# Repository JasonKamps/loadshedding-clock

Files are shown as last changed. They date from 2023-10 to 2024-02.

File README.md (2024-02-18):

# Loadshedding Clock

A timer that counts down to the next scheduled blackout.

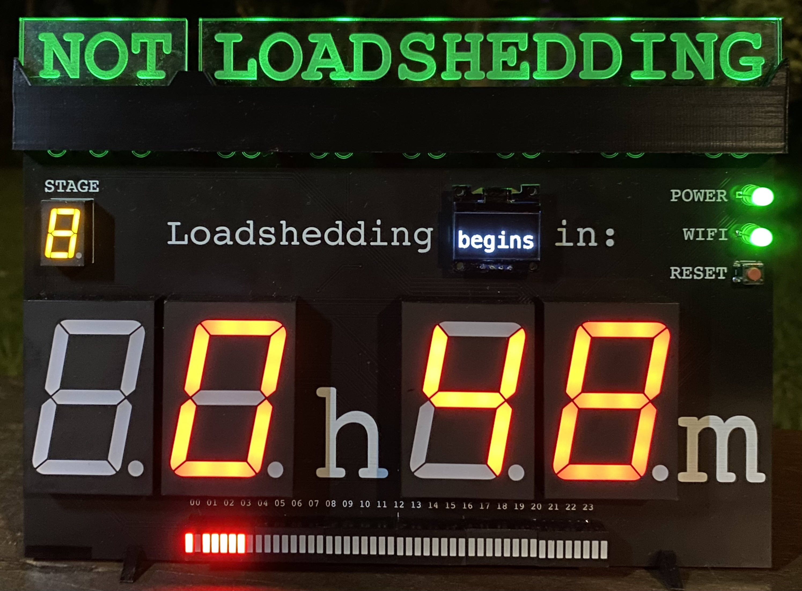
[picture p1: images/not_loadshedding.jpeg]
Front view not loadshedding

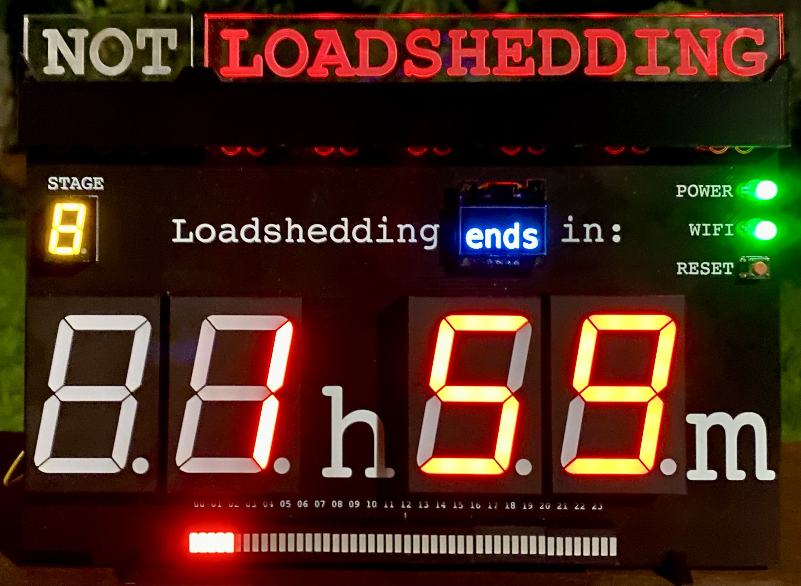
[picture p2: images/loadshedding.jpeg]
Front view loadshedding

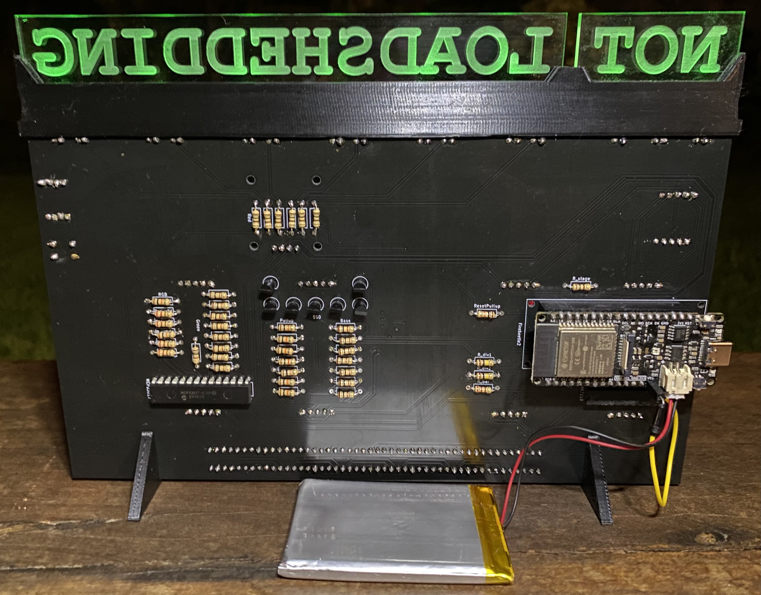
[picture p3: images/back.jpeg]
Back view

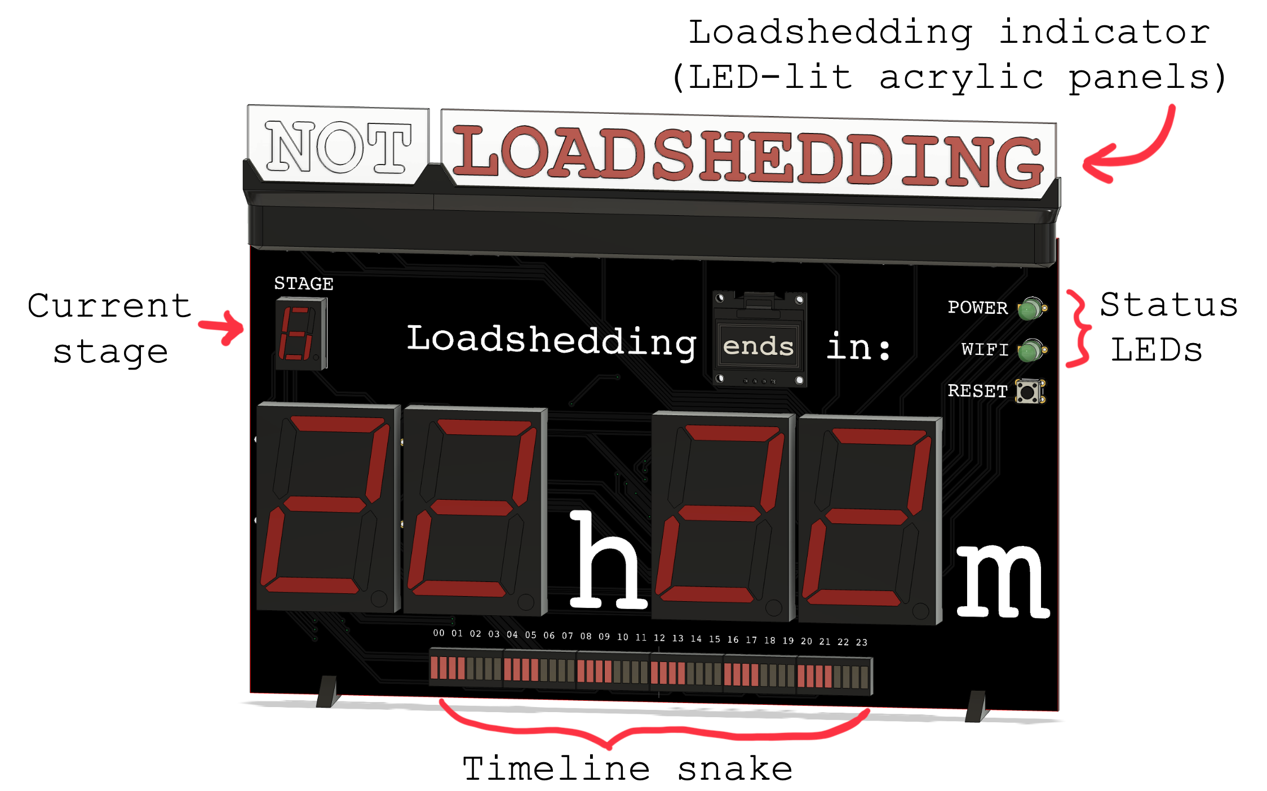
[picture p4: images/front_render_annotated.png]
CAD render


The clock is based on an ESP32 microcontroller, and it obtains loadshedding information from the [EskomSePush API](https://eskomsepush.gumroad.com/l/api).

All code is written in C++ using the [Arduino framework](https://www.arduino.cc/reference/en/) and [PlatformIO](https://platformio.org/). The code is available in [/loadshedding-clock-code/src](./loadshedding-clock-code/src).

The PCB schematics and board layouts can be found in [/PCB](./PCB).

CAD files for the 3D-printable parts can be found in [/3D](./3D).

## Why did I make this?

In South Africa, our national power utility (Eskom) [fails to generate](https://en.wikipedia.org/wiki/South_African_energy_crisis) sufficient electricity to supply the entire country with power. As a result, rolling blackouts have been implemented to ration electricity. Each day, regions of the country are disconnected from the power grid for hours at a time. Any given area typically experiences blackouts lasting 2 to 4 hours, multiple times each day. 

Fortunately, these blackout events are scheduled in advance. The timings of the blackouts change daily, and it can be challenging to keep track of when loadshedding will occur. Many South Africans rely on the [EskomSePush](https://esp.info/) app to stay informed about the loadshedding in their area. I wanted to take this one step further and make it even easier to stay informed. By simply glancing at the loadshedding clock, one can immediately see when the next blackout will occur.

## How does it work?

The clock is based on an ESP32 microcontroller. It connects to the internet via WiFi, and it obtains loadshedding information from the [EskomSePush API](https://eskomsepush.gumroad.com/l/api). The clock is powered by a 5V USB power supply, and it is equipped with a battery backup. 

When the clock is powered on for the first time, it broadcasts its own WiFi network. When the user connects to this network and visits a site hosted by the clock, they can input their WiFi credentials, suburb, and EskomSePush API key.

The clock then displays the loadshedding information for the given suburb, automatically updating its schedule every 30 minutes. If the internet connection is lost, it will continue to display the last schedule that it received from the API.

## What's next?

Future versions may include the following:

- [x] ~~Get the clock working~~
- [x] ~~LED timeline~~
- [x] ~~LED-lit acrylic panel~~
- [x] ~~Design PCB~~
- [ ] Simplified 7-segment display circuitry
- [ ] Notification buzzer
- [ ] Capacitive touch input

## Bill of Materials

| Part | Quantity |
|---| -- |
| [FireBeetle 2 ESP32 Microcontroller](https://www.robotics.org.za/DFR0654) | 1 |
| [3.7V LiPo Battery](https://www.robotics.org.za/DTP605068) | 1 |
| [I2C OLED Display](https://www.robotics.org.za/OLED096W) | 1 |
| [MCP23017 IO Expander](https://www.robotics.org.za/MCP23017) | 1 |
| [MAX7219 Display Driver](https://www.robotics.org.za/MAX7219-DIP) | 1 |
| [7 Segment Display 1.8" Common Cathode](https://www.robotics.org.za/7SEG-018-GRE) | 4 |
| [7 Segment Display 0.56" Common Cathode](https://www.robotics.org.za/7SEG-056-RED) | 1 |
| [BC557 PNP Transistor](https://www.robotics.org.za/BC557) | 7 |
| [Bar graph LED](https://www.robotics.org.za/BAR8-RED) | 6 |
| [Green 5mm LED](https://www.robotics.org.za/LED-05-GRN-17) | 9 |
| [Red 5mm LED](https://www.robotics.org.za/LED-RED-5MM) | 6 |
| [Push button](https://www.robotics.org.za/TAC-66-H) | 1 |
| [RGB LED](https://www.robotics.org.za/RGB-8MM-CC) | 2 |
| [Adjustable DC power supply](https://www.robotics.org.za/CJ-615) | 1 |
| [DC jack to USB C converter](https://www.robotics.org.za/JACK-USBC) | 1 |
| [100kΩ resistor](https://www.robotics.org.za/RES-100K-50) | 2 |
| [10kΩ resistor](https://www.robotics.org.za/RES-10K-025) | 8 |
| [1kΩ resistor](https://www.robotics.org.za/RES-1K-50) | 18 |
| [220Ω resistor](https://www.robotics.org.za/RES-220E-50) | 5 |
| [100Ω resistor](https://www.robotics.org.za/RES-100E-50) | 7 |

## Video overview
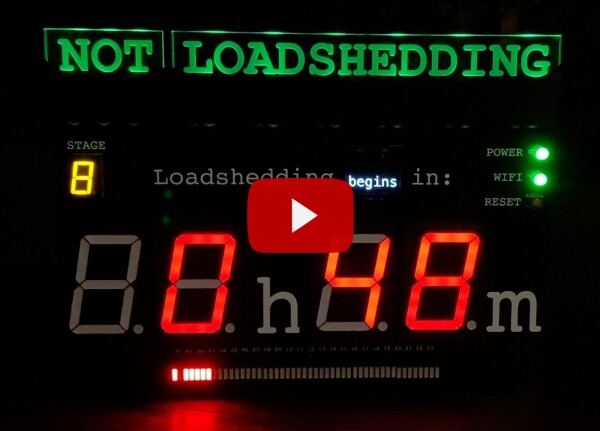
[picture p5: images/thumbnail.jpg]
I made a loadshedding clock (https://youtu.be/v7MFmr7yhXo "I made a loadshedding clock")


## Breadboard Prototype
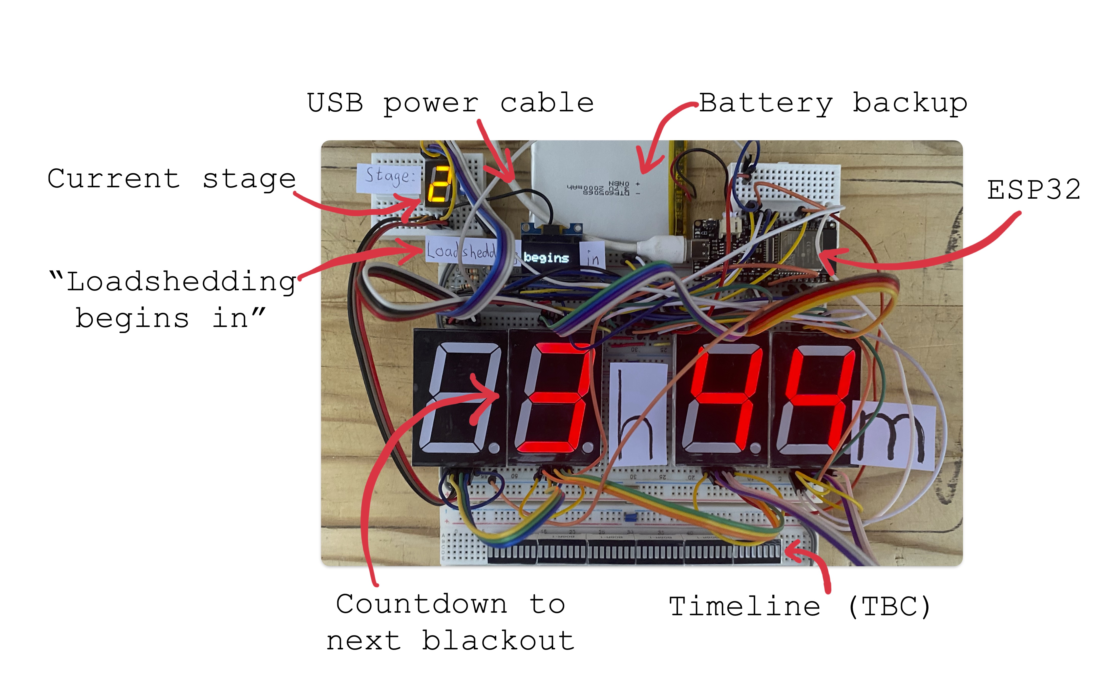
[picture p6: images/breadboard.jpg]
Breadboard prototype


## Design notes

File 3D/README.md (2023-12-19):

## 3D CAD files

This directory contains the 3D CAD files for the supporting parts of the loadshedding clock.

The files were designed in [Fusion 360](https://www.autodesk.com/products/fusion-360/overview).

## Loadshedding indicator adapter and Feet

The loadshedding indicator adapter is a 3D-printed part that allows the loadshedding indicator (acrylic panels) to be mounted on the clock.

The feet are 3D-printed parts that allow the clock to stand upright.

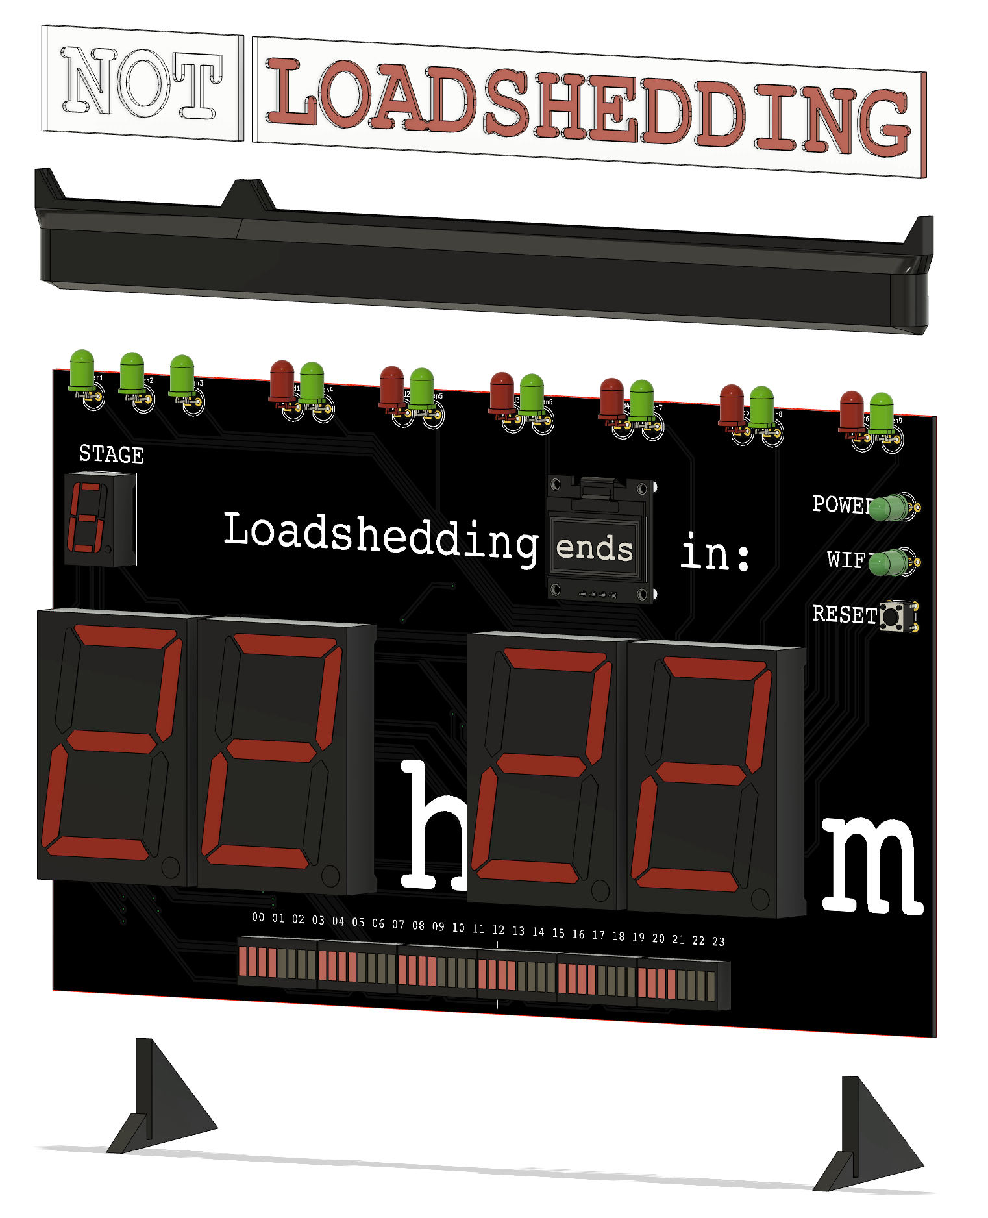
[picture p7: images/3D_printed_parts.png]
3D printed parts


## Loadshedding indicator sign

[/sign](./sign) contains image files for the loadshedding indicator sign. These files can be used to laser cut the sign from acrylic.

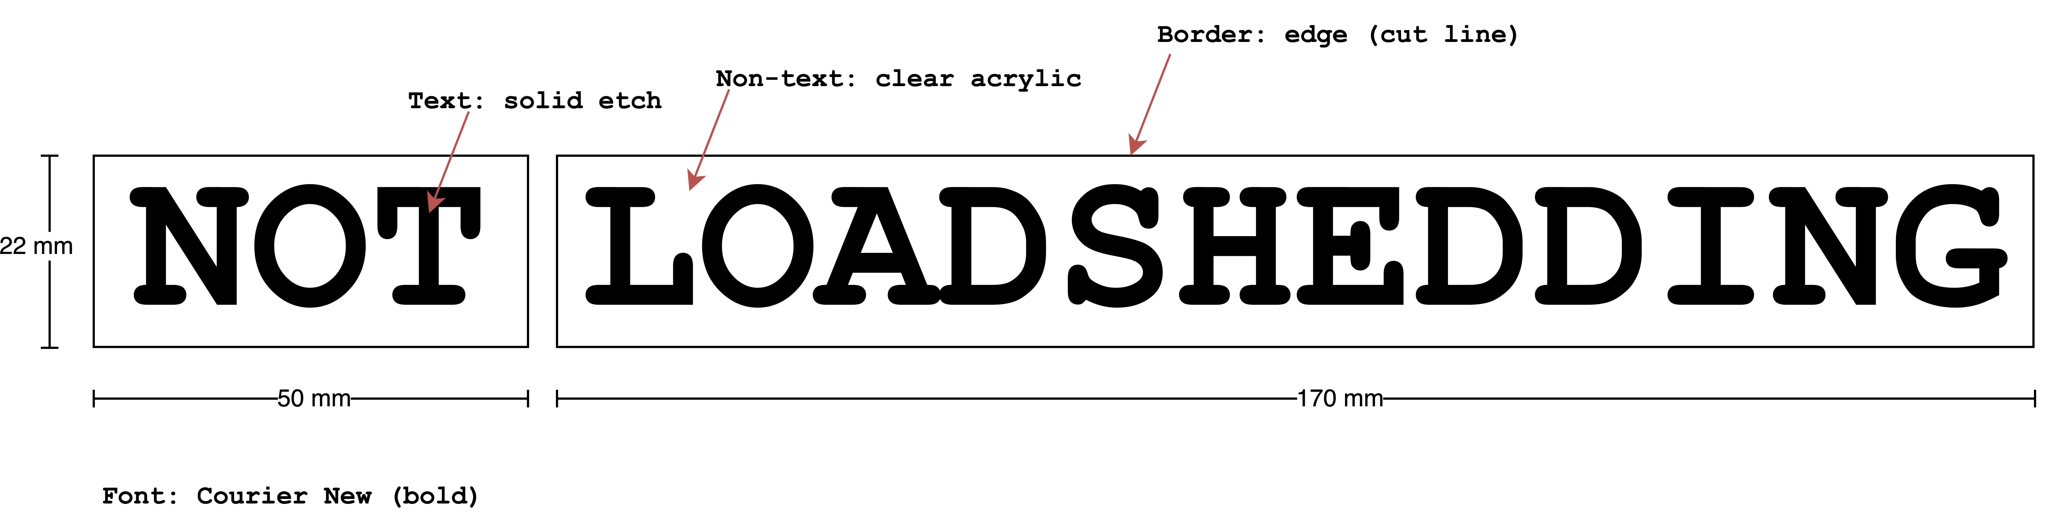
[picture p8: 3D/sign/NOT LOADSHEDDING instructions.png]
Loadshedding indicator sign


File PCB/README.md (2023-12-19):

# PCB files

This directory contains the KiCad project files for the PCB.

Gerber files are available in [/outputs](./outputs).

I used [JLCPCB](https://jlcpcb.com/) to manufacture the PCB.

## Schematic

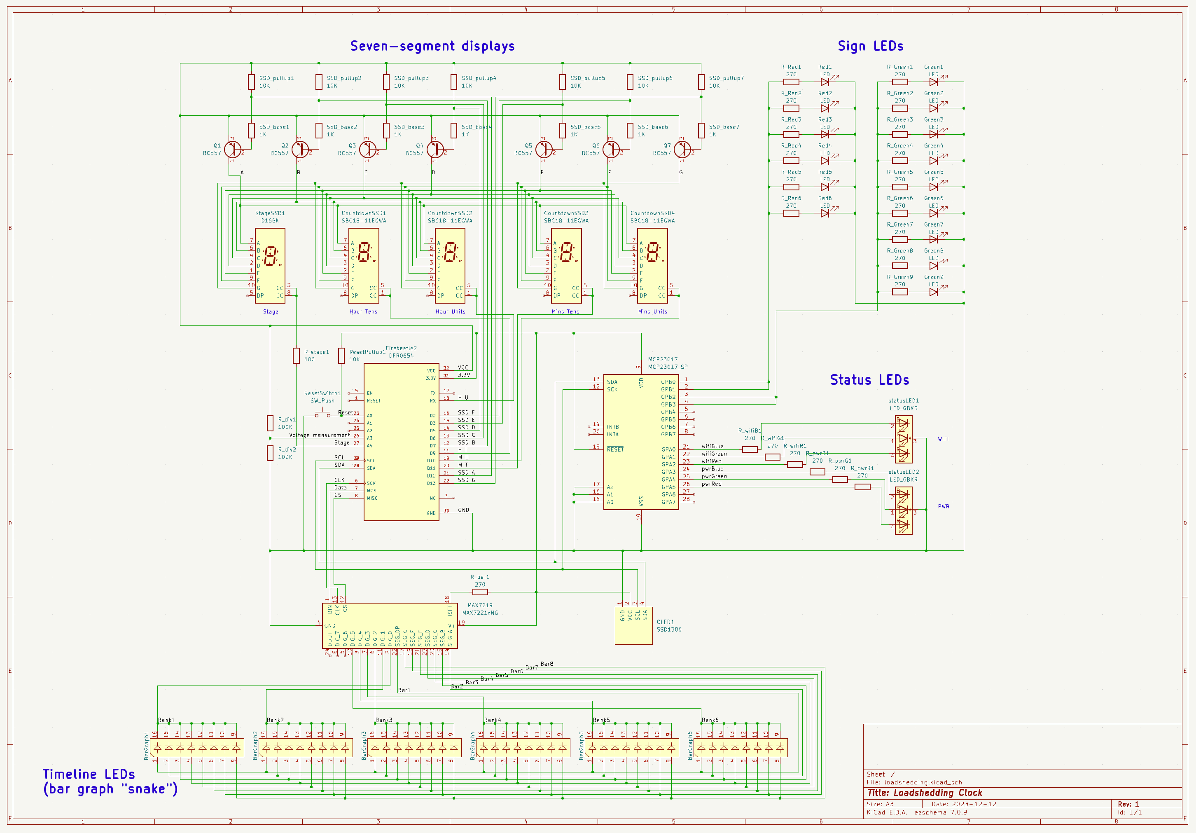
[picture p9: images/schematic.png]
Schematic


## Board

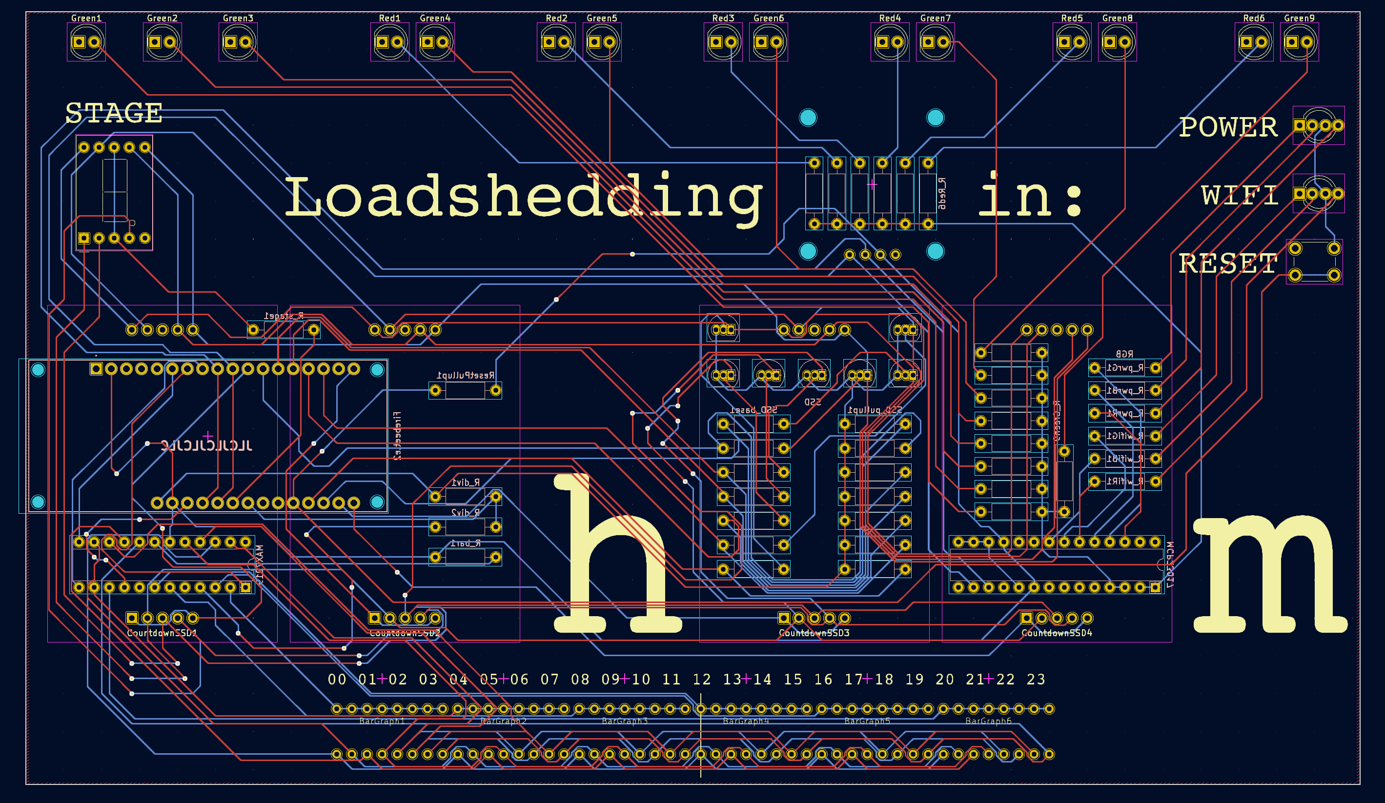
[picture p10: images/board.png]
Board


## 3D renders

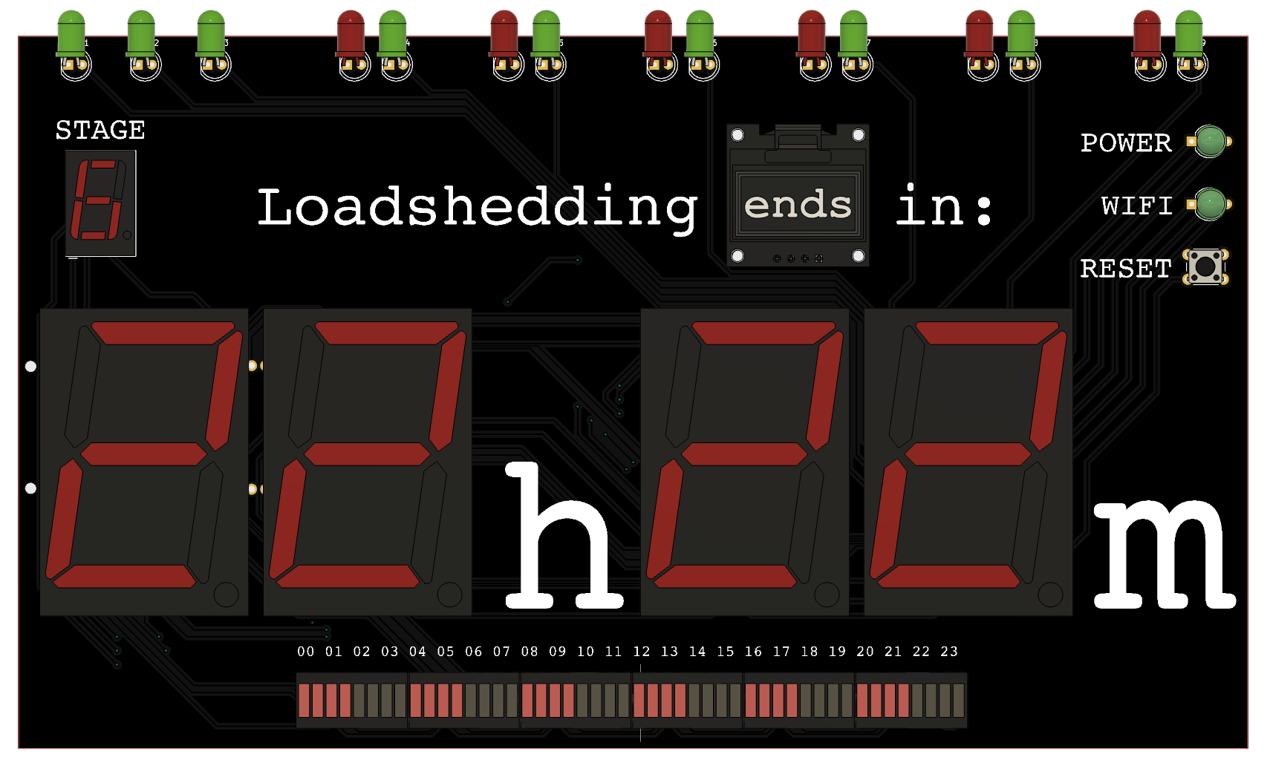
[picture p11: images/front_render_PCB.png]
Front render

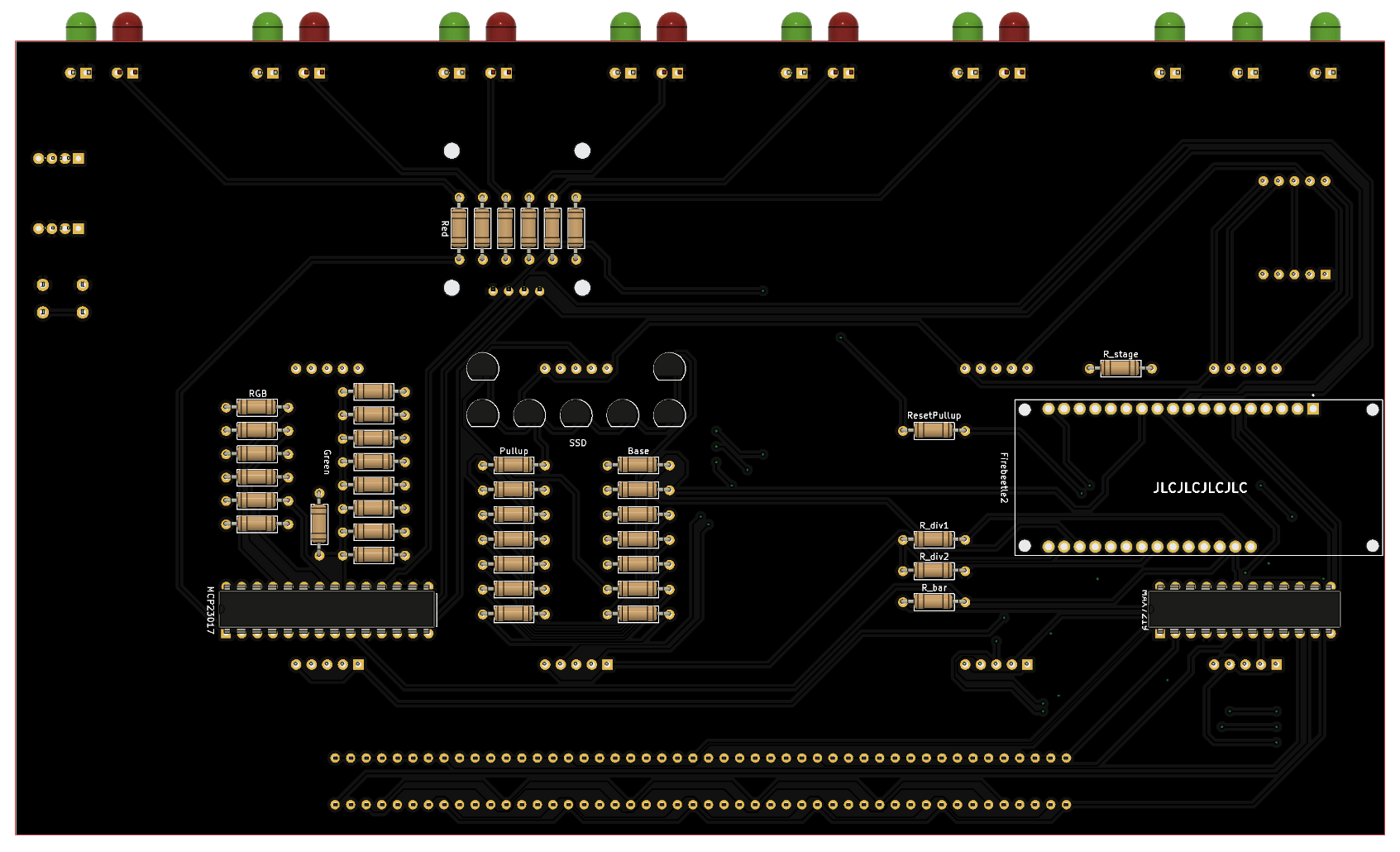
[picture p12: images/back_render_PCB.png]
Back render


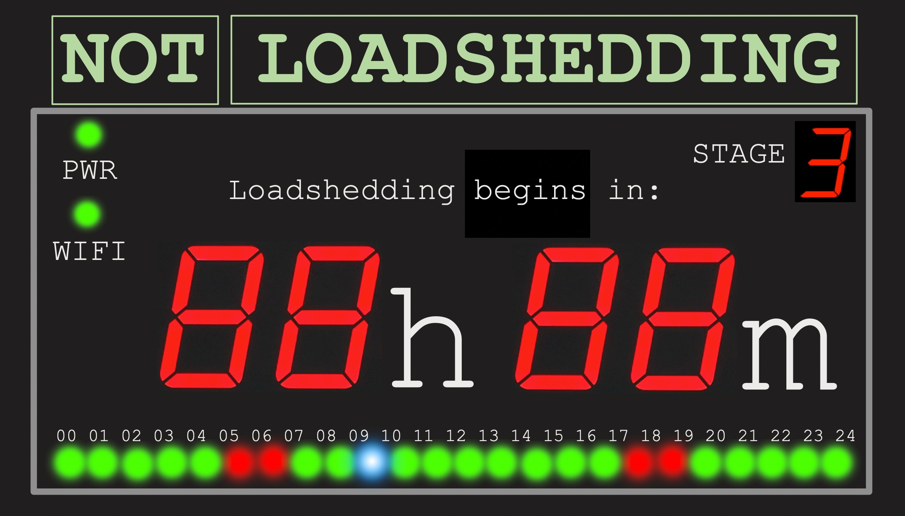
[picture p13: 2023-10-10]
images/visual_design.jpg

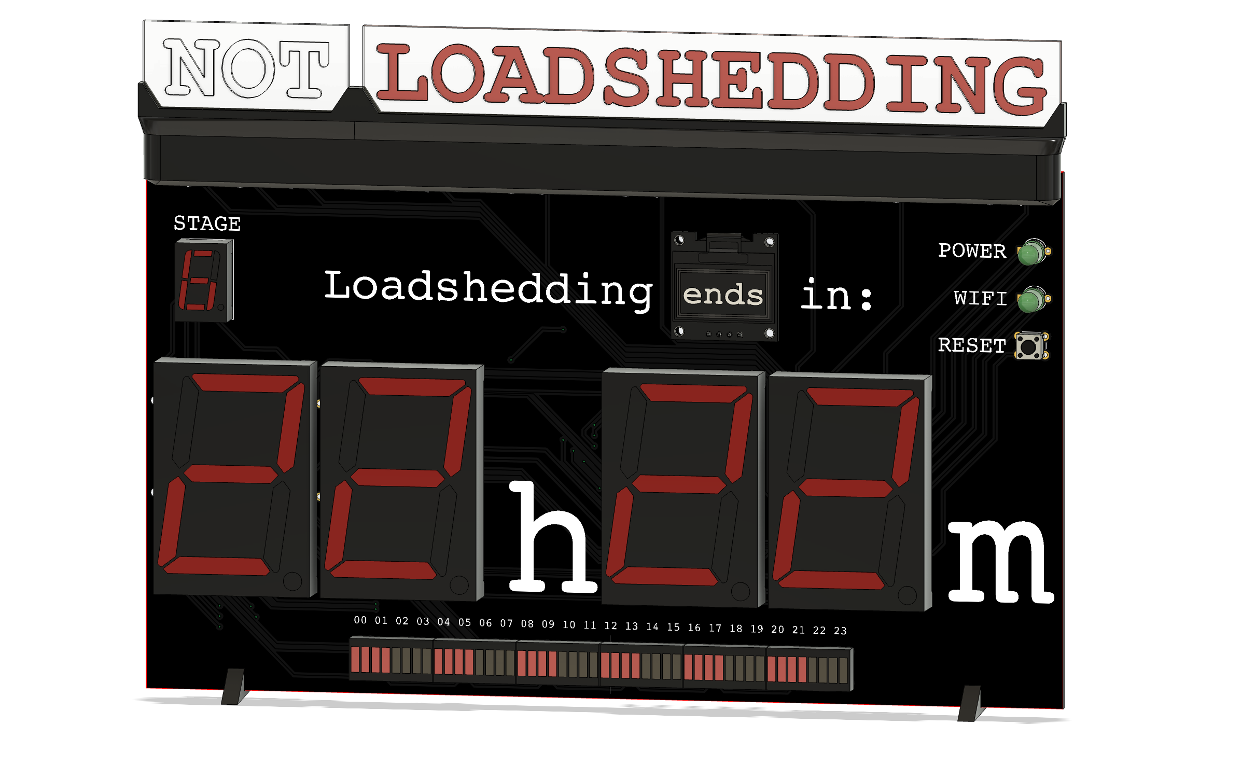
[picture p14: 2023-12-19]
images/front_render.png

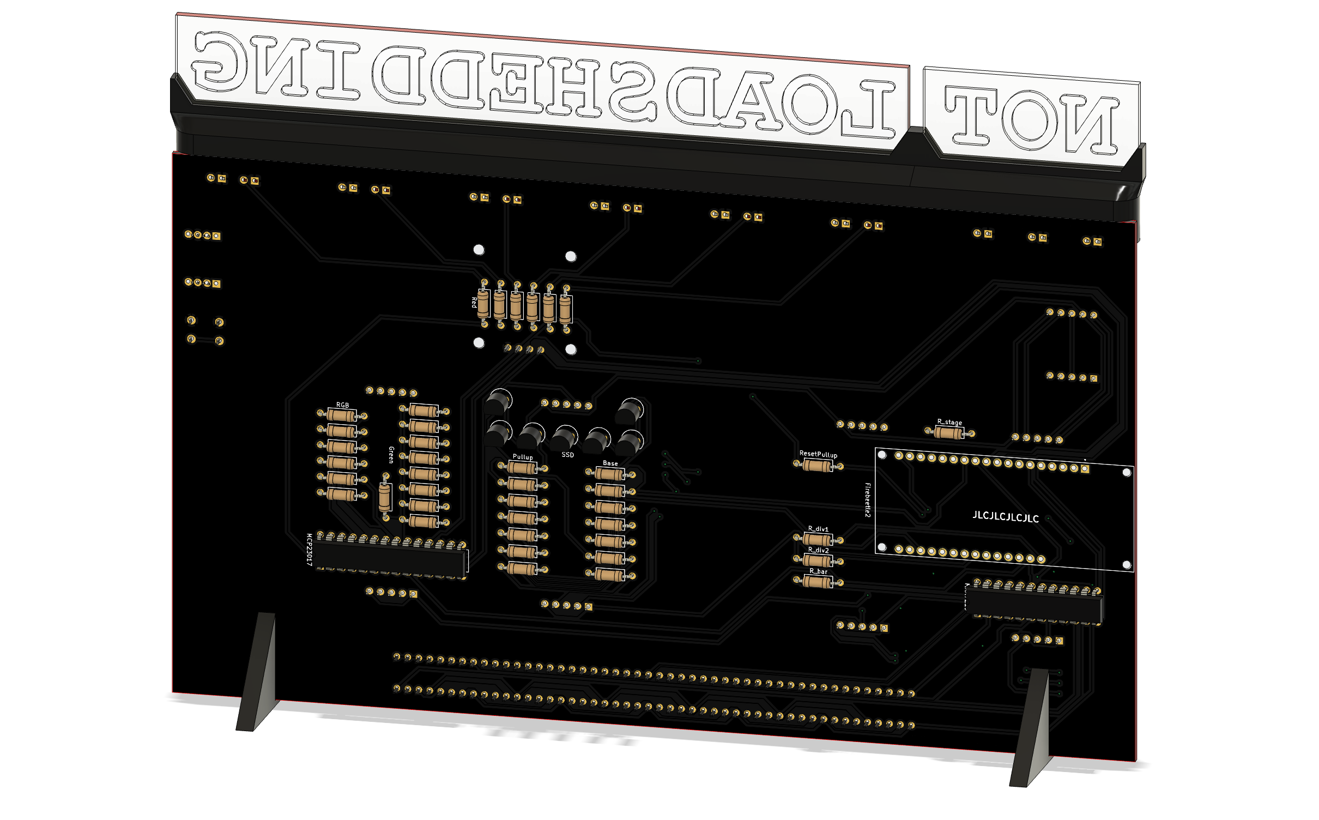
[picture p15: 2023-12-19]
images/back_render.png

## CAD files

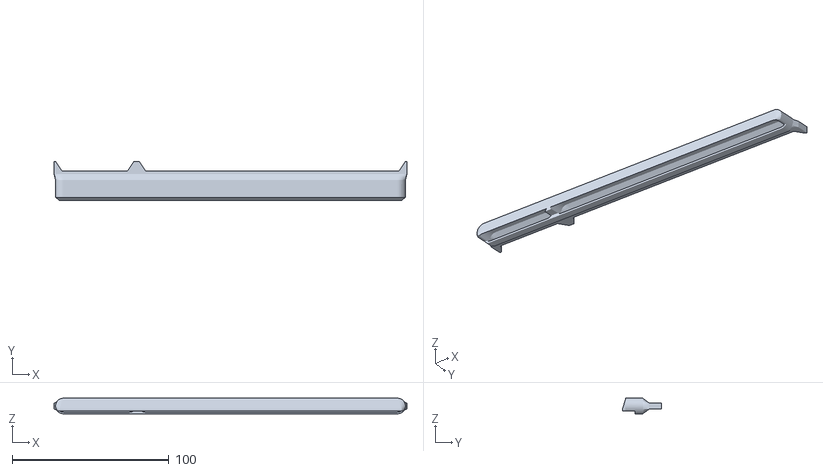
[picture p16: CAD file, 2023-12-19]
3D/sign adapter.stl
225.5 x 25.0 x 10.0

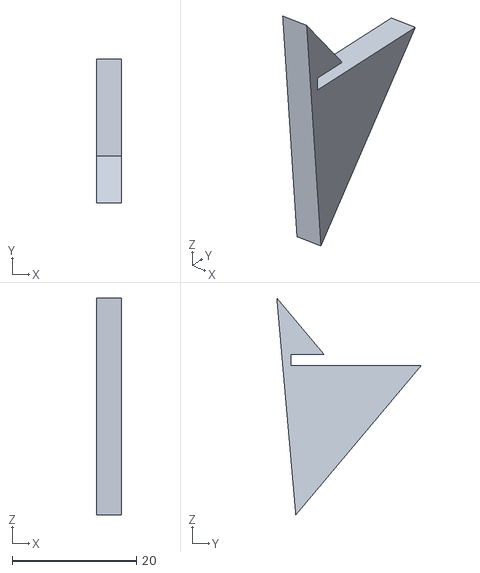
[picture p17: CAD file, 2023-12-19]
3D/foot.stl
4.00 x 23.2 x 34.9

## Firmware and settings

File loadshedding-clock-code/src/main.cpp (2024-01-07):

#include <Arduino.h>
#include "oled.h"
#include "connectWiFi.h"
#include "storage.h"
#include "dateTime.h"
#include "api.h"
#include "schedule.h"
#include "ssd.h"
#include "timeline.h"
#include "Led.h"

const int RESET_PIN = 36;
const int API_CALL_INTERVAL = 30; // minutes

// Input voltage measurement
const int VIN_MEASURE_PIN = 35;
const float BATTERY_VOLTAGE_THRESHOLD = 3.5; // volts

Adafruit_MCP23X17 mcp;

LED wifiLED(2, 1, 0);
LED pwrLED(5, 4, 3);
LED signLEDs(8, 10, 14);

Schedule schedule;

time_t lastEventRetrievalTime = 0;

hw_timer_t *ssdTimer = NULL;

float getInputVoltage()
{
  return analogRead(VIN_MEASURE_PIN) / 4095.0 * 3.3 * 2; // 2x voltage divider
}

// ISR to refresh seven-segment displays
void IRAM_ATTR ssdISR()
{
  refreshSSDs();
}

void setup()
{
  // serial
  Serial.begin(19200);

  while (!Serial)
  {
    // wait for serial port to connect
  }

  Serial.println("Starting up...");

  // OLED
  setupOLED();

  // VIN measurement
  pinMode(VIN_MEASURE_PIN, INPUT);
  Serial.println("VIN voltage: " + String(getInputVoltage()) + " V");

  // status LEDs
  wifiLED.setup();
  pwrLED.setup();
  signLEDs.setup();

  // test LEDs
  wifiLED.turnBlue();
  pwrLED.turnBlue();
  delay(200);
  wifiLED.turnGreen();
  pwrLED.turnGreen();
  signLEDs.turnGreen();
  delay(200);
  wifiLED.turnRed();
  pwrLED.turnRed();
  signLEDs.turnRed();
  delay(200);
  pwrLED.turnOff();
  signLEDs.turnOff();

  // display power source
  getInputVoltage() > BATTERY_VOLTAGE_THRESHOLD ? pwrLED.turnGreen() : pwrLED.turnRed();

  // timeline
  setupTimeline();
  sweepTimelineLEDs();

  // seven-segment display refresh timer (500 Hz)
  ssdTimer = timerBegin(0, 80, true); // 80 prescaler gives 1 MHz
  timerAttachInterrupt(ssdTimer, &ssdISR, true);
  timerAlarmWrite(ssdTimer, 2000, true); // 2000 microseconds gives 500 Hz
  timerAlarmEnable(ssdTimer);

  // test seven-segment displays
  testSSDs();

  // storage
  setupStorage();

  // reset button
  pinMode(RESET_PIN, INPUT_PULLUP);
  if (digitalRead(RESET_PIN) == LOW)
  {
    // short press
    displayText("Resetting WiFi...");
    delay(5000);
    resetWiFi();

    if (digitalRead(RESET_PIN) == LOW)
    {
      // long press
      displayText("Resetting storage...", 10, false);
      delay(5000);
      resetStorage();
    }
  }

  // WiFi
  boolean customParamsSaved = setupWiFi();
  isWiFiConnected() ? wifiLED.turnGreen() : wifiLED.turnRed();

  // display user info from storage
  displayText("API: " + readString("apiToken"), 0, 1, true);
  displayText("User area: " + readString("userAreaName"), 30, 1, true, false);
  delay(2000);

  // date and time
  setupDateTime();

  // API
  if (customParamsSaved)
  {
    // only retrieve area if custom parameters were saved (don't want to waste API calls)
    retrieveArea();
  }

  // retrieve events if sufficient time has passed since last retrieval
  lastEventRetrievalTime = readTime("lastRetrieval");
  if (getUnixTime() - lastEventRetrievalTime > (API_CALL_INTERVAL * 60))
  {
    Serial.println("Retrieving events. It has been more than " + String(API_CALL_INTERVAL) + " minutes since last retrieval.");
    retrieveEvents();
    time_t now = getUnixTime();
    writeTime("lastRetrieval", now);
    lastEventRetrievalTime = now;
  }
  else
  {
    Serial.println("Not retrieving events. It has only been " + String((getUnixTime() - lastEventRetrievalTime) / 60.0) + " minutes since last retrieval.");
  }

  // schedule
  schedule.update();
  schedule.isCurrentlyLoadshedding() ? signLEDs.turnRed() : signLEDs.turnGreen();

  // read and print events
  DynamicJsonDocument doc = readEvents();
  serializeJsonPretty(doc, Serial);
  Serial.println();

  // display area info from storage
  displayText("Area: " + readString("areaName"), 0, 1, true);
  displayText("Area ID: " + readString("areaId"), 30, 1, true, false);
  delay(2000);

  // display VIN voltage
  clearDisplay();
  displayText("VIN: " + String(getInputVoltage()) + " V", 0, 1, true, false);
  delay(1000);

  clearDisplay();
}

void loop()
{
  // update values to display on seven-segment displays
  int secondsUntilNextTransition = schedule.getSecondsUntilNextTransition();
  // Serial.println(secondsUntilNextTransition);
  int highestStage = schedule.getHighestUpcomingStage();
  updateSSDs(secondsUntilNextTransition, highestStage);

  if (secondsUntilNextTransition >= 0)
  {
    // display "ends" on OLED if currently loadshedding, "begins" if not yet loadshedding
    schedule.isCurrentlyLoadshedding() ? displayEnds() : displayBegins();
  }
  else
  {
    // no upciming events, display "suspended" on OLED
    displayText("suspended", 20, 2);
  }

  // update timeline
  updateTimeline(schedule);
  flashCurrentTimelineLED();

  // update LEDs
  schedule.isCurrentlyLoadshedding() ? signLEDs.turnRed() : signLEDs.turnGreen();
  isWiFiConnected() ? wifiLED.turnGreen() : wifiLED.turnRed();
  getInputVoltage() > BATTERY_VOLTAGE_THRESHOLD ? pwrLED.turnGreen() : pwrLED.turnRed();

  delay(1000);
}

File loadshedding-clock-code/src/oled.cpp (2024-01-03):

#include <SPI.h>
#include <Wire.h>
#include <Adafruit_GFX.h>
#include <Adafruit_SSD1306.h>
#include "oled.h"

#define SCREEN_WIDTH 128 // OLED width, in pixels
#define SCREEN_HEIGHT 64 // OLED width, in pixels

#define SCREEN_ADDRESS 0x3C // 0x3C for 128x64

// declare SSD1306 display connected to I2C
Adafruit_SSD1306 display(SCREEN_WIDTH, SCREEN_HEIGHT, &Wire, -1);

// 128x64px bitmap array
// made using https://kleki.com/ and https://notisrac.github.io/FileToCArray/
static const unsigned char eishkom[] PROGMEM = {
    0x00, 0x00, 0x00, 0x00, 0x00, 0x00, 0x00, 0x00, 0x00, 0x00, 0x00, 0x00, 0x00, 0x00, 0x00, 0x00,
    0x00, 0x00, 0x00, 0x00, 0x00, 0x00, 0x00, 0x00, 0x00, 0x00, 0x00, 0x00, 0x00, 0x00, 0x00, 0x00,
    0x00, 0x00, 0x00, 0x00, 0x00, 0x00, 0x00, 0x00, 0x00, 0x00, 0x00, 0x00, 0x00, 0x00, 0x00, 0x00,
    0x00, 0x00, 0x00, 0x00, 0x00, 0x00, 0x00, 0x00, 0x00, 0x00, 0x00, 0x00, 0x00, 0x00, 0x00, 0x00,
    0x00, 0x00, 0x00, 0x00, 0x00, 0x00, 0x00, 0x00, 0x00, 0x00, 0x00, 0x00, 0x00, 0x00, 0x00, 0x00,
    0x00, 0x00, 0x00, 0x00, 0x00, 0x00, 0x00, 0x00, 0x00, 0x00, 0x00, 0x00, 0x00, 0x00, 0x00, 0x00,
    0x00, 0x00, 0x00, 0x00, 0x00, 0x00, 0x00, 0x00, 0x00, 0x00, 0x00, 0x00, 0x00, 0x00, 0x00, 0x00,
    0x00, 0x00, 0x00, 0x00, 0x00, 0x00, 0x00, 0x00, 0x00, 0x00, 0x00, 0x00, 0x00, 0x00, 0x00, 0x00,
    0x00, 0x00, 0x00, 0x00, 0x00, 0x00, 0x00, 0x00, 0x00, 0x00, 0x00, 0x00, 0x00, 0x00, 0x00, 0x00,
    0x00, 0x00, 0x00, 0x00, 0x00, 0x00, 0x00, 0x00, 0x00, 0x00, 0x00, 0x00, 0x00, 0x00, 0x00, 0x00,
    0x00, 0x00, 0x00, 0x00, 0x00, 0x00, 0x00, 0x00, 0x00, 0x00, 0x00, 0x00, 0x00, 0x00, 0x00, 0x00,
    0x00, 0x00, 0x00, 0x00, 0x00, 0x00, 0x00, 0x00, 0x00, 0x00, 0x00, 0x00, 0x00, 0x00, 0x00, 0x00,
    0x00, 0x00, 0x00, 0x00, 0x00, 0x00, 0x00, 0x00, 0x00, 0x00, 0x00, 0x00, 0x00, 0x00, 0x00, 0x00,
    0x00, 0x00, 0x00, 0x00, 0x00, 0x00, 0x00, 0x00, 0x00, 0x00, 0x00, 0x00, 0x00, 0x00, 0x00, 0x00,
    0x00, 0x00, 0x00, 0x00, 0x00, 0x00, 0x00, 0x00, 0x00, 0x00, 0x00, 0x00, 0x00, 0x00, 0x00, 0x00,
    0x00, 0x00, 0x00, 0x00, 0x00, 0x00, 0x00, 0x00, 0x20, 0x00, 0x00, 0x00, 0x00, 0x00, 0x00, 0x00,
    0x00, 0x00, 0x00, 0x00, 0x00, 0x00, 0x30, 0x00, 0x78, 0x00, 0x00, 0x00, 0x00, 0x00, 0x00, 0x00,
    0x00, 0x00, 0x00, 0x00, 0x00, 0x00, 0xf8, 0x00, 0x78, 0x00, 0x00, 0x00, 0x00, 0x00, 0x00, 0x00,
    0x00, 0x3f, 0xfe, 0x00, 0x00, 0x00, 0xf8, 0x00, 0x78, 0x00, 0x00, 0x00, 0x00, 0x00, 0x00, 0x00,
    0x07, 0xff, 0xfe, 0x00, 0x00, 0x00, 0xf8, 0x00, 0x78, 0x00, 0x00, 0x00, 0x00, 0x00, 0x00, 0x00,
    0x0f, 0xff, 0xfe, 0x00, 0x00, 0x00, 0xf8, 0x00, 0x78, 0x00, 0x00, 0x00, 0x00, 0x00, 0x00, 0x00,
    0x0f, 0xff, 0xfe, 0x00, 0x00, 0x00, 0xf8, 0x00, 0x78, 0x00, 0x00, 0x00, 0x00, 0x00, 0x00, 0x00,
    0x1f, 0xf8, 0x00, 0x00, 0x00, 0x00, 0xf8, 0x00, 0x78, 0x07, 0x80, 0x00, 0x00, 0x00, 0x00, 0x00,
    0x0f, 0x00, 0x00, 0x30, 0x00, 0x00, 0xf8, 0x00, 0x78, 0x07, 0x80, 0x00, 0x00, 0x00, 0x00, 0x00,
    0x0f, 0x00, 0x00, 0x78, 0x00, 0x00, 0xf8, 0x00, 0x78, 0x0f, 0x80, 0x00, 0x00, 0x00, 0x00, 0x00,
    0x0f, 0x00, 0x00, 0x78, 0x00, 0x00, 0xf8, 0x00, 0x78, 0x1f, 0x00, 0x00, 0x30, 0x01, 0x60, 0x00,
    0x0f, 0x00, 0x00, 0x78, 0x00, 0x00, 0x78, 0x00, 0x78, 0x3f, 0x00, 0xf0, 0x7b, 0x8f, 0xf0, 0x00,
    0x0f, 0x00, 0x00, 0x30, 0x00, 0x00, 0xf8, 0x00, 0x78, 0x3e, 0x03, 0xf8, 0x7f, 0xff, 0xf8, 0x00,
    0x0f, 0x80, 0x00, 0x00, 0x00, 0x00, 0x79, 0x80, 0x7c, 0xfe, 0x07, 0xf8, 0x7f, 0xff, 0xfc, 0x00,
    0x0f, 0x80, 0x00, 0x00, 0x03, 0xfc, 0x7f, 0xf0, 0x7d, 0xfc, 0x07, 0xfc, 0x7f, 0xff, 0xfe, 0x00,
    0x07, 0x80, 0x38, 0x00, 0x0f, 0xfe, 0x7f, 0xf8, 0x7f, 0xf8, 0x0f, 0xfc, 0x7f, 0xfe, 0x3f, 0x00,
    0x07, 0x80, 0xfc, 0x1c, 0x1f, 0xfe, 0x7f, 0xfc, 0x3f, 0xf0, 0x1f, 0xbe, 0x7e, 0x7c, 0x1f, 0x00,
    0x07, 0xff, 0xfc, 0x3c, 0x3f, 0xfc, 0x3f, 0xfc, 0x3f, 0xf8, 0x1f, 0x1e, 0x7e, 0x7c, 0x0f, 0x80,
    0x07, 0xff, 0xfc, 0x3e, 0x3f, 0x00, 0x3f, 0x3e, 0x3f, 0xf8, 0x3e, 0x1f, 0x3e, 0x3c, 0x0f, 0x80,
    0x07, 0xff, 0xf0, 0x3c, 0x3c, 0x00, 0x3e, 0x3e, 0x3f, 0xfc, 0x3e, 0x1f, 0x3e, 0x7c, 0x07, 0xc0,
    0x07, 0xff, 0xc0, 0x3e, 0x3f, 0x80, 0x3e, 0x1e, 0x3e, 0x7c, 0x3e, 0x0f, 0x3e, 0x3e, 0x07, 0xc0,
    0x03, 0xc8, 0x00, 0x3c, 0x3f, 0xfe, 0x3e, 0x1f, 0x3e, 0x3e, 0x3e, 0x0f, 0x3e, 0x3e, 0x03, 0xc0,
    0x03, 0xc0, 0x00, 0x3e, 0x1f, 0xff, 0x3e, 0x0f, 0x3e, 0x1f, 0x3c, 0x0f, 0x3e, 0x3e, 0x03, 0xc0,
    0x03, 0xc0, 0x00, 0x3c, 0x1f, 0xff, 0x3e, 0x0f, 0x3e, 0x1f, 0x3e, 0x1f, 0x1f, 0x3e, 0x03, 0xc0,
    0x03, 0xc0, 0x00, 0x3c, 0x07, 0xff, 0x1e, 0x0f, 0x3e, 0x0f, 0x9e, 0x1f, 0x1f, 0x3e, 0x03, 0xe0,
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

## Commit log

2023-07-23 Replace FS storage with preferences storage
    [connectWiFi.cpp, main.cpp, oled.cpp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]
2023-10-08 Switch to FireBeetle2 & remove BCD driver
    The seven-segment displays are now controlled via a series of transistors instead of the binary-coded decimal driver.
2023-10-26 Add timeline
    LED bar graph timeline to show upcoming loadshedding events
2023-12-04 Remove leading zeros from countdown
    Also fix layout of timeline and fix leftmost SSD "ghost" display
    [ssd.cpp]
2023-12-05 Add status LEDs
    Also add flashing timeline LED
2023-12-06 Fix WiFi status LED
    Also adjust battery threshold
    [main.cpp]
2023-12-19 Add PCB files
    [loadshedding-B_Cu.gbl, loadshedding-B_Mask.gbs, loadshedding-B_Paste.gbp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]
2023-12-19 Add 3D CAD files
    [foot.stl, sign adapter.stl]
2023-12-19 Add PCB and 3D READMEs
    Also update root README.md and add more images (3D renders).
2024-01-03 Update resistor values
    [loadshedding.kicad_sch]
2024-01-03 Update README.md
    Add images and update BOM
2024-02-18 Update BOM
